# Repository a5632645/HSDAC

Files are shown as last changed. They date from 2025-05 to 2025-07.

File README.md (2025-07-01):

# CH32V305-UAC2
ch32v305fbp6 + es9018k2m + opa1678 usb dac  
> [!NOTE]
> Due to using inexpensive components, the clock has approximately a 200 Hz error. Additionally, the MCLK GPIO speed exceeds the maximum 50 MHz limit at 192 kHz.
> If desired, you can use an external crystal for the I2S MCLK clock.

> [!NOTE]
> this dac only support 48k,96k,192k 32bits, dsd and other formats are not considered

> [!NOTE]
> This DAC only supports high-speed connections, so do not connect it through a USB hub.
> Any clicks that occur are a result of the computer not sending data within a given time. Therefore, you may hear clicks during periods of high system load.
# IMAGE
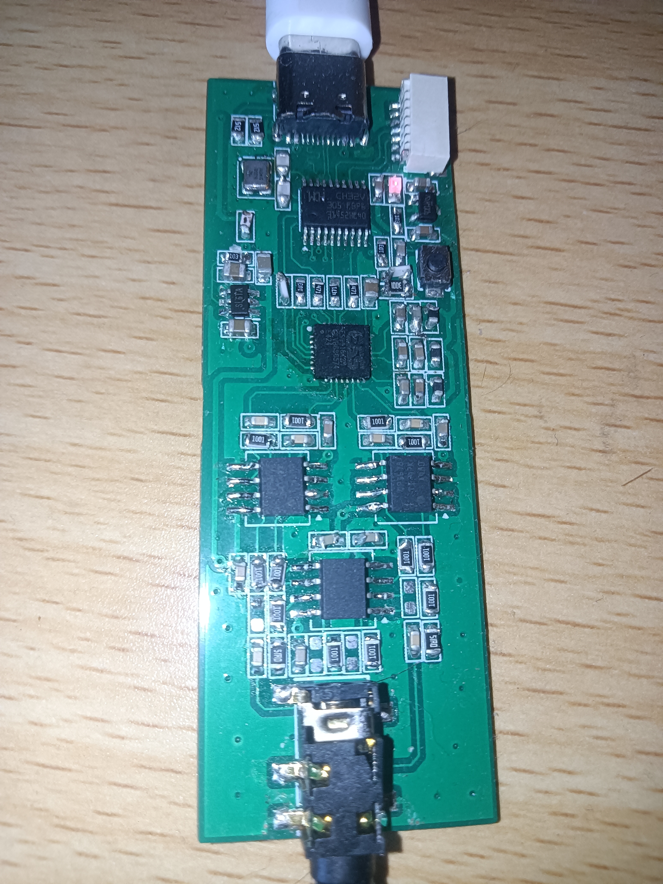
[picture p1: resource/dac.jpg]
DAC Image


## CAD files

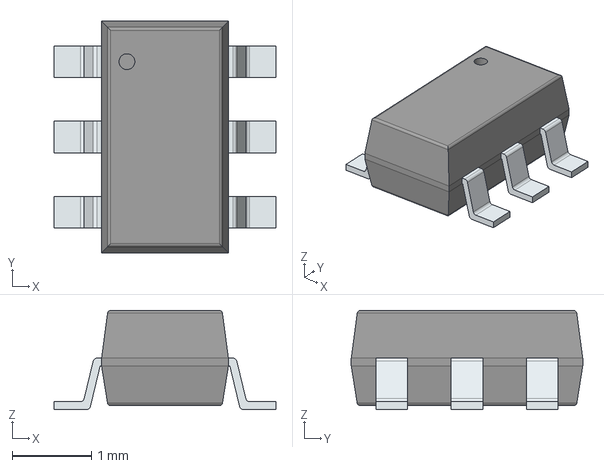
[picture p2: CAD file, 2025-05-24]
hardware/3rd/3d/SGM3204YN6G_TR.stp
2.80 x 2.92 x 1.25 mm
PinsArrayLR

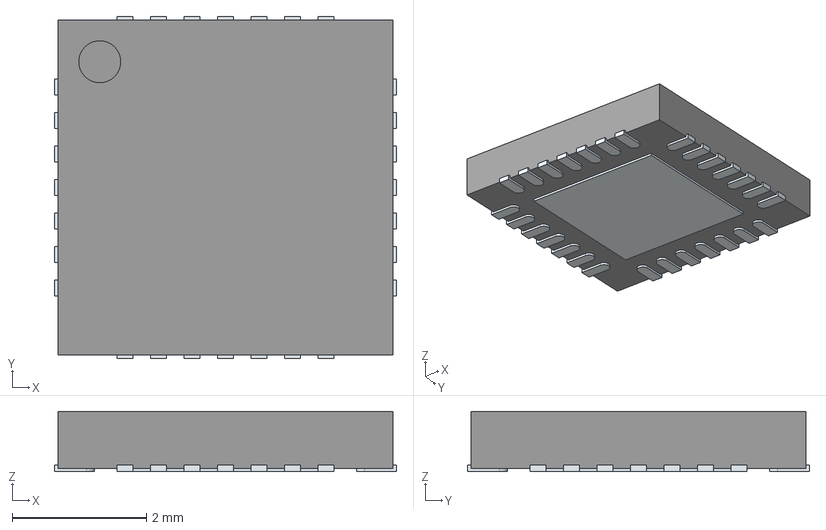
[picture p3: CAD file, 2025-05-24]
hardware/3rd/3d/ES9018K2M.stp
5.10 x 5.10 x 0.9 mm
ThermalPin
PinsArrayLR
PinsArrayTB

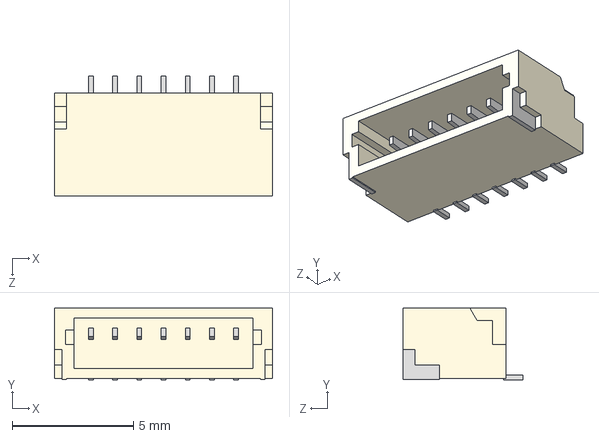
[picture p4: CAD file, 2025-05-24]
hardware/3rd/3d/SM07B-SRSS-TB_LF__SN_.stp
9.00 x 2.96 x 4.95 mm

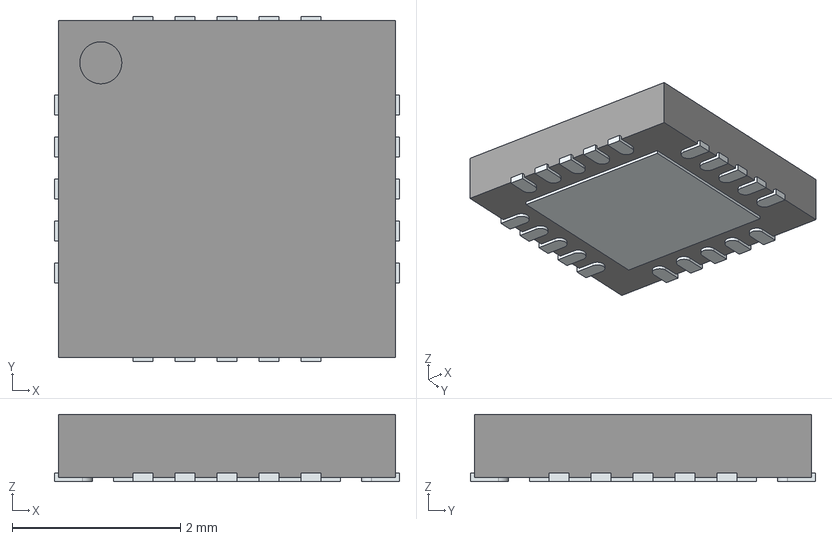
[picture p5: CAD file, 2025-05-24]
hardware/3rd/3d/TPA6130A2RTJR.stp
4.10 x 4.10 x 0.8 mm
ThermalPin
PinsArrayLR
PinsArrayTB

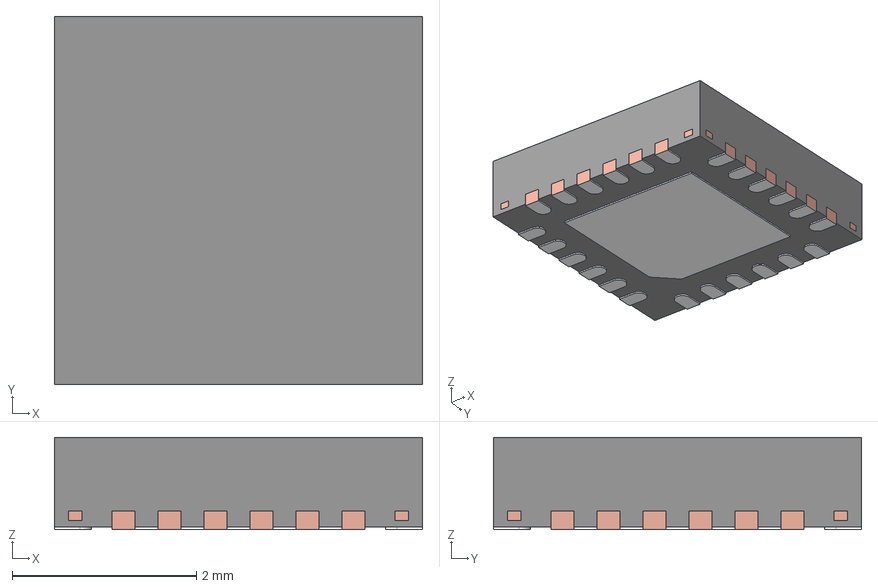
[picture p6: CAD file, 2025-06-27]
hardware/3rd/3d/TPS65131RGER.stp
4.00 x 4.00 x 1.00 mm
BODY-QFN
FRAME-RGE0024B
PIN1-ID

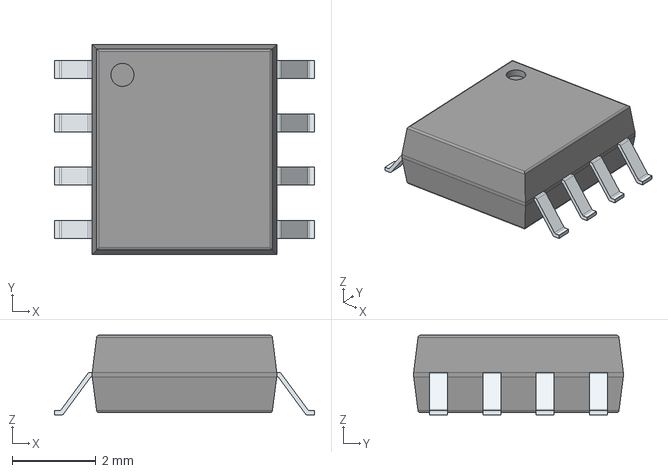
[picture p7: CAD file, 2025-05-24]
hardware/3rd/3d/M62429FP.stp
6.20 x 5.00 x 1.90 mm
PinsArrayLR

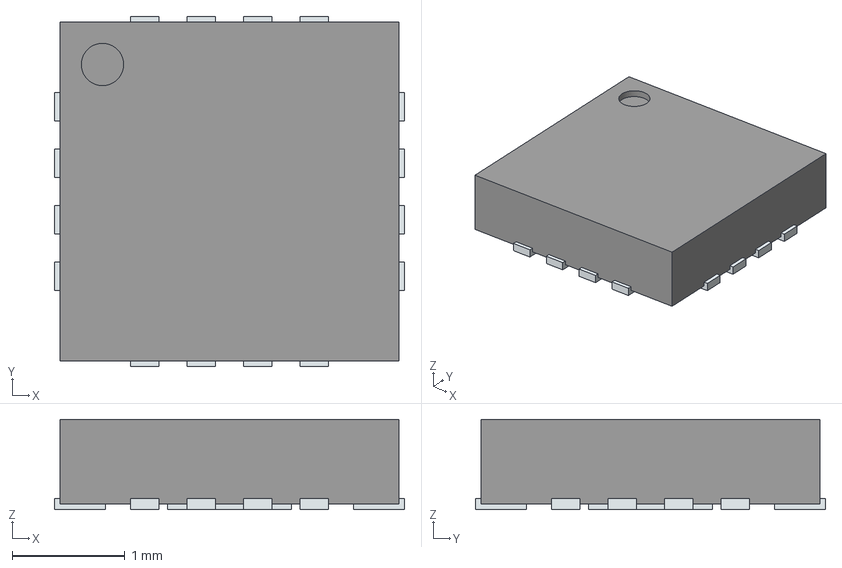
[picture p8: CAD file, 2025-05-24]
hardware/3rd/3d/MAX97220AETE+T.stp
3.10 x 3.10 x 0.8 mm
ThermalPin
PinsArrayLR
PinsArrayTB

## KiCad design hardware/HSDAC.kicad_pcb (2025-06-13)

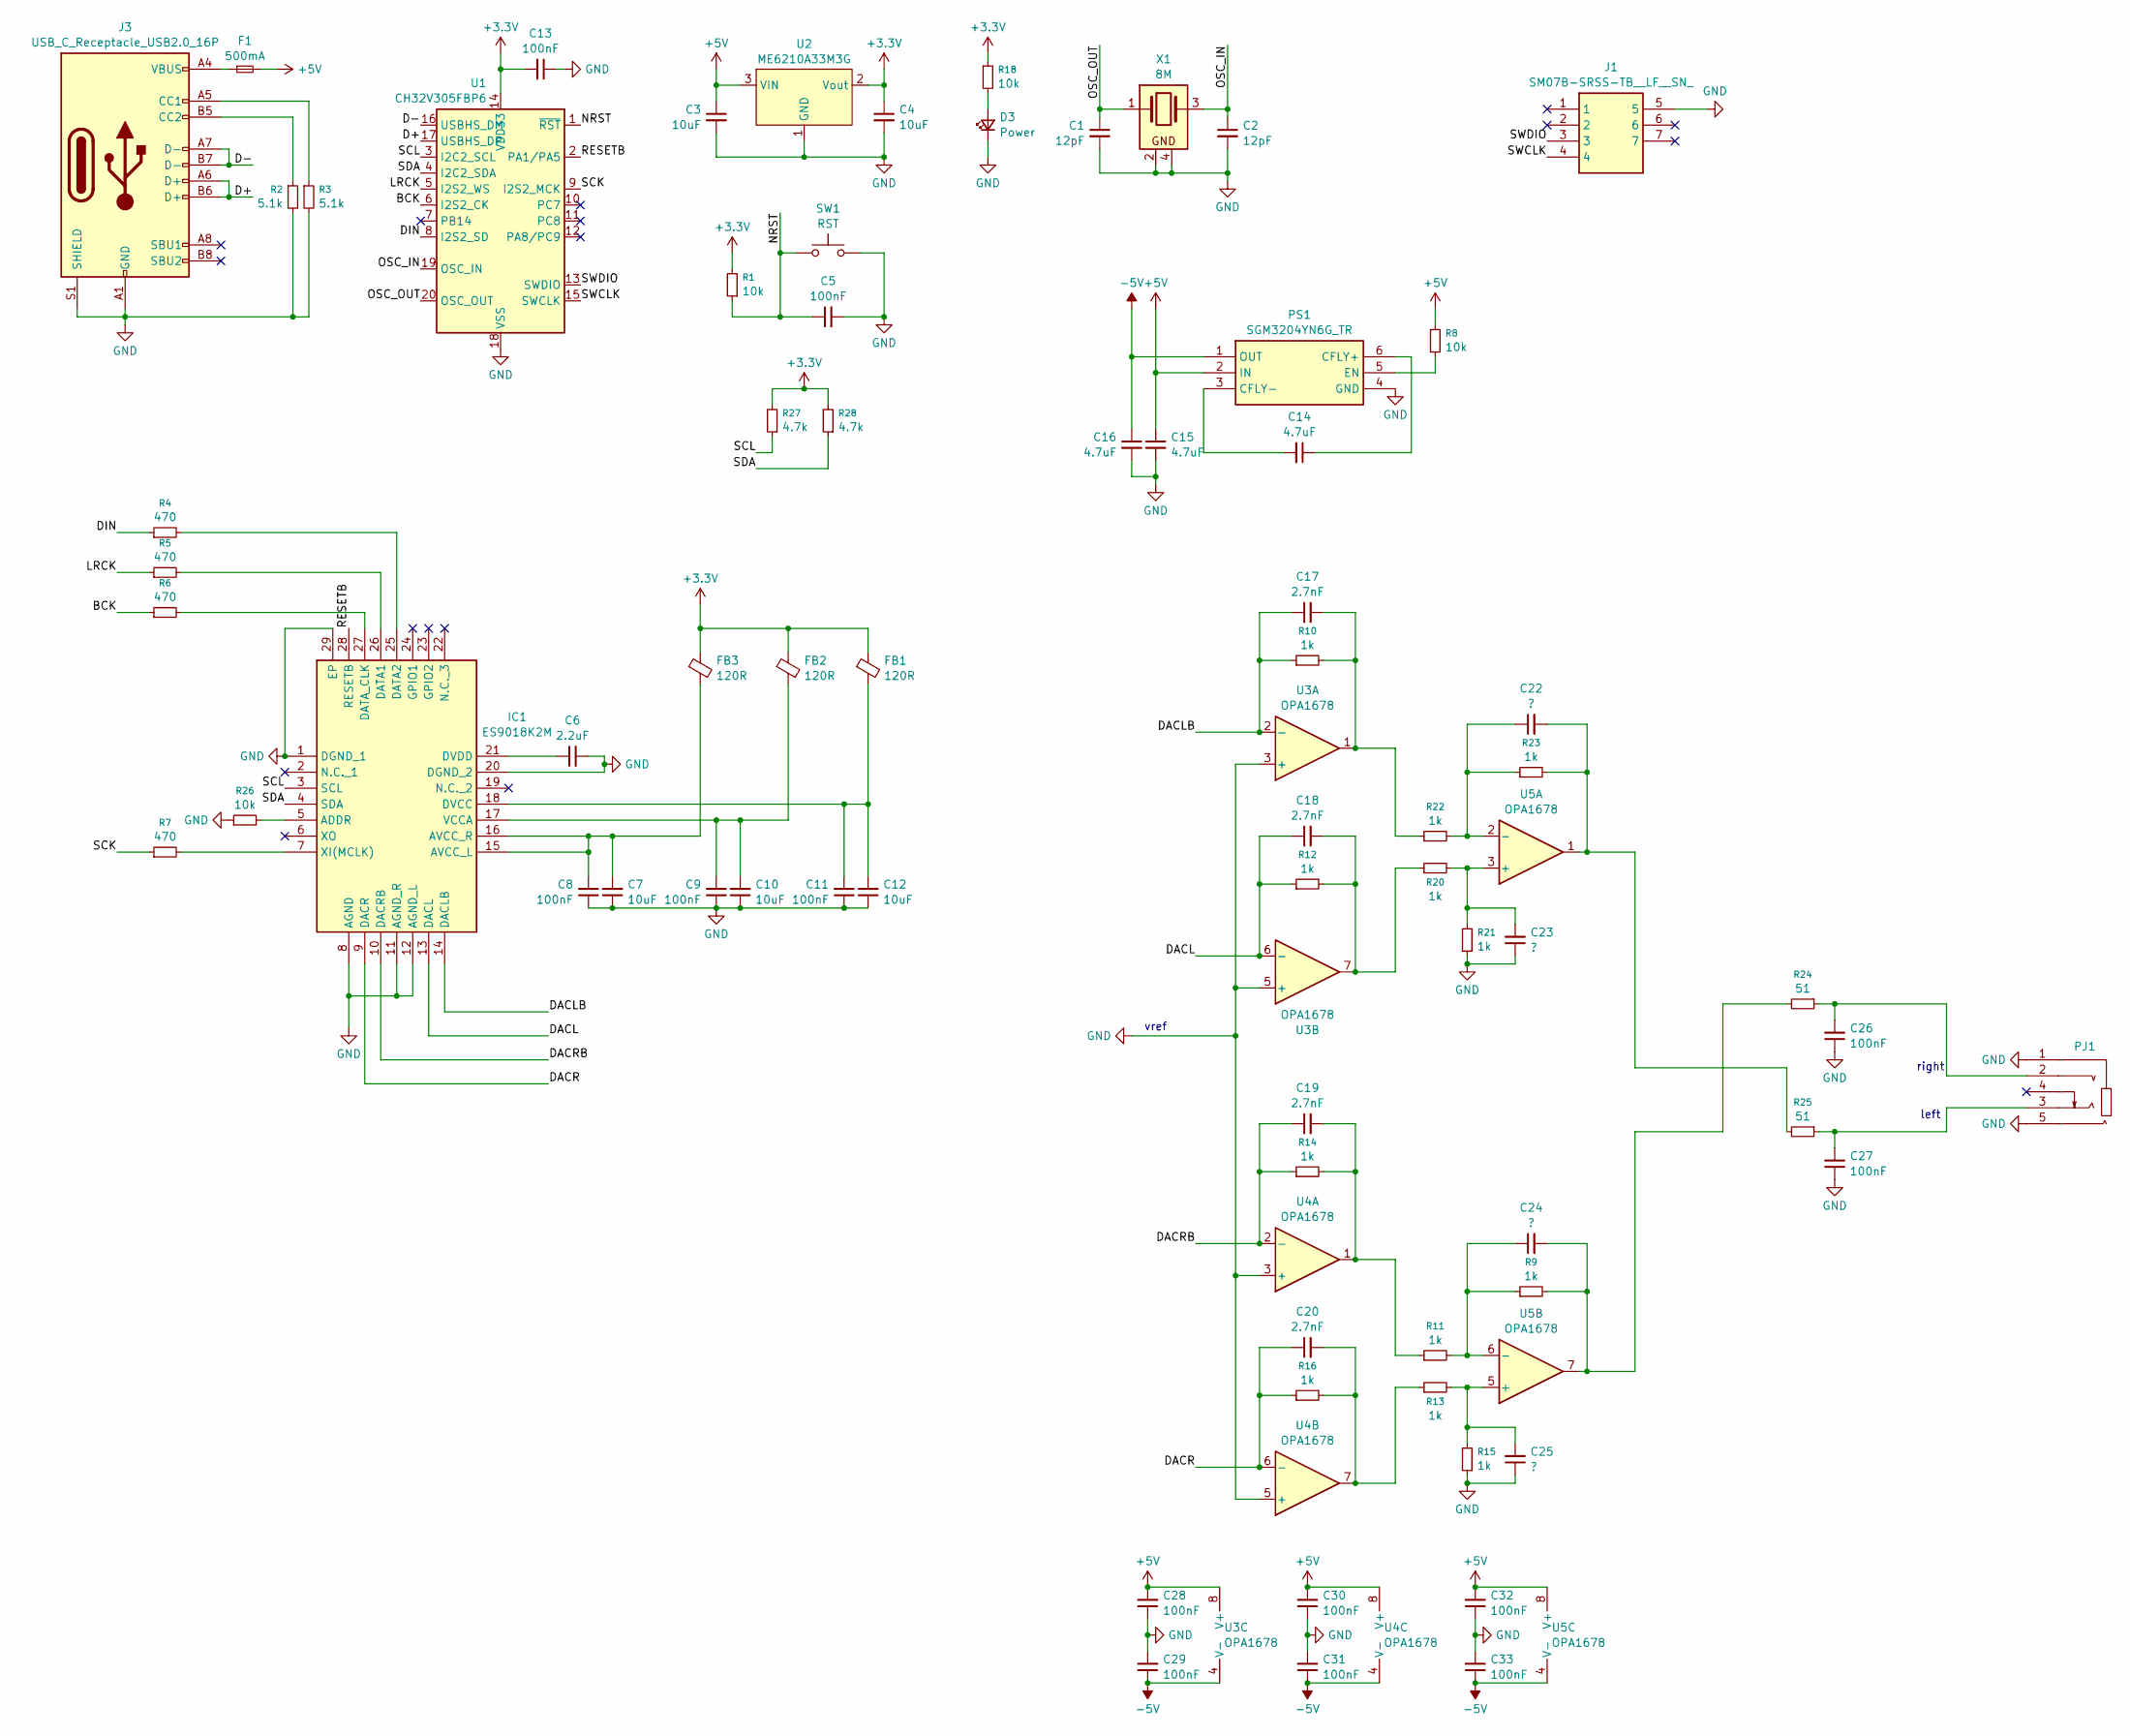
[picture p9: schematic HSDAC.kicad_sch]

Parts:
C1, C2: 12pF; C_0603_1608Metric_Pad1.05x0.95mm_HandSolder
C3, C4, C7, C10, C12: 10uF; C_0603_1608Metric_Pad1.05x0.95mm_HandSolder
C5, C8, C9, C11, C13, C26, C27, C28, C29, C30, C31, C32, C33: 100nF; C_0603_1608Metric_Pad1.05x0.95mm_HandSolder
C6: 2.2uF; C_0603_1608Metric_Pad1.05x0.95mm_HandSolder
C14, C15, C16: 4.7uF; C_0603_1608Metric_Pad1.05x0.95mm_HandSolder
C17, C18, C19, C20: 2.7nF; C_0603_1608Metric_Pad1.05x0.95mm_HandSolder
C22, C23, C24, C25: ?; C_0603_1608Metric_Pad1.05x0.95mm_HandSolder
D3: Power; LED_0805_2012Metric
F1: 500mA; Fuse_0603_1608Metric
FB1, FB2, FB3: 120R; Ferrite_0603_1608Metric
IC1: ES9018K2M; QFN50P500X500X90-29N-D; Manufacturer_Part_Number ES9018K2M; Mouser Part Number 460-ES9018K2M
J1: SM07B-SRSS-TB__LF__SN_; SM07B-SRSS-TB; Manufacturer_Part_Number SM07B-SRSS-TB (LF)(SN)
J3: USB_C_Receptacle_USB2.0_16P; USB_C_Receptacle_G-Switch_GT-USB-7010ASV
PJ1: AUDIO-IN-SMD_PJ-327A_C22355751; Manufacturer Part PJ-327A; LCSC Part Name PJ-327A
PS1: SGM3204YN6G_TR; SOT95P280X125-6N; Manufacturer_Part_Number SGM3204YN6G/TR
R1, R8, R18, R26: 10k; R_0603_1608Metric_Pad0.98x0.95mm_HandSolder
R2, R3: 5.1k; R_0603_1608Metric_Pad0.98x0.95mm_HandSolder
R4, R5, R6, R7: 470; R_0603_1608Metric_Pad0.98x0.95mm_HandSolder
R9, R10, R11, R12, R13, R14, R15, R16, R20, R21, R22, R23: 1k; R_0603_1608Metric_Pad0.98x0.95mm_HandSolder
R24, R25: 51; R_0603_1608Metric_Pad0.98x0.95mm_HandSolder
R27, R28: 4.7k; R_0603_1608Metric_Pad0.98x0.95mm_HandSolder
SW1: RST; SW-SMD_L4.0-W3.0-LS4.8-1
U1: CH32V305FBP6; TSSOP-20_4.4x6.5mm_P0.65mm
U2: ME6210A33M3G; SOT-23
U3, U4, U5: OPA1678; SOIC-8_3.9x4.9mm_P1.27mm
X1: 8M; Crystal_SMD_3225-4Pin_3.2x2.5mm

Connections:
+3.3V: C4.1, C13.2, FB1.1, FB2.1, FB3.1, R1.2, R18.1, R27.2, R28.2, U1.14 (VDD33), U2.2 (Vout)
+5V: C3.1, C15.1, C28.2, C30.2, C32.2, F1.2, PS1.2 (IN), R8.2, U2.3 (VIN), U3.8 (V+), U4.8 (V+), U5.8 (V+)
-5V: C16.1, C29.1, C31.1, C33.1, PS1.1 (OUT), U3.4 (V-), U4.4 (V-), U5.4 (V-)
/BCK: R6.1, U1.6 (I2S2_CK)
/D+: J3.A6 (D+), J3.B6 (D+), U1.17 (USBHS_DP)
/D-: J3.A7 (D-), J3.B7 (D-), U1.16 (USBHS_DM)
/DACL: C18.1, IC1.13 (DACL), R12.1, U3.6 (-)
/DACLB: C17.1, IC1.14 (DACLB), R10.1, U3.2 (-)
/DACR: C20.1, IC1.9 (DACR), R16.1, U4.6 (-)
/DACRB: C19.1, IC1.10 (DACRB), R14.1, U4.2 (-)
/DIN: R4.1, U1.8 (I2S2_SD)
/LRCK: R5.1, U1.5 (I2S2_WS)
/NRST: C5.1, R1.1, SW1.1, U1.1 (~RST)
/OSC_IN: C2.1, U1.19 (OSC_IN), X1.3
/OSC_OUT: C1.1, U1.20 (OSC_OUT), X1.1
/RESETB: IC1.28 (RESETB), U1.2 (PA1/PA5)
/SCK: R7.1, U1.9 (I2S2_MCK)
/SCL: IC1.3 (SCL), R27.1, U1.3 (I2C2_SCL)
/SDA: IC1.4 (SDA), R28.1, U1.4 (I2C2_SDA)
/SWCLK: J1.4, U1.15 (SWCLK)
/SWDIO: J1.3, U1.13 (SWDIO)
GND: C1.2, C2.2, C3.2, C4.2, C5.2, C6.2, C7.1, C8.1, C9.1, C10.1, C11.1, C12.1, C13.1, C15.2, C16.2, C23.1, C25.1, C26.1, C27.1, C28.1, C29.2, C30.1, C31.2, C32.1, C33.2, D3.1 (K), IC1.1 (DGND_1), IC1.8 (AGND), IC1.11 (AGND_R), IC1.12 (AGND_L), IC1.20 (DGND_2), IC1.29 (EP), J1.5, J3.A1 (GND), J3.A12 (GND), J3.B1 (GND), J3.B12 (GND), J3.S1 (SHIELD), PJ1.1, PJ1.5, PS1.4 (GND), R2.2, R3.2, R15.1, R21.1, R26.1, SW1.2, U1.18 (VSS), U2.1 (GND), U3.3 (+), U3.5 (+), U4.3 (+), U4.5 (+), X1.2, X1.4
unnamed: C17.2, R10.2, R22.1, U3.1
unnamed: C18.2, R12.2, R20.1, U3.7
unnamed: C19.2, R11.1, R14.2, U4.1
unnamed: C20.2, R13.1, R16.2, U4.7
unnamed: C22.2, R23.2, R25.2, U5.1
unnamed: C24.2, R9.2, R24.2, U5.7
unnamed: C26.2, PJ1.2, R24.1
unnamed: C27.2, PJ1.3, R25.1
unnamed: D3.2 (A), R18.2
unnamed: F1.1, J3.A4 (VBUS), J3.A9 (VBUS), J3.B4 (VBUS), J3.B9 (VBUS)
unnamed: IC1.5 (ADDR), R26.2
unnamed: C7.2, C8.2, FB3.2, IC1.15 (AVCC_L), IC1.16 (AVCC_R)
unnamed: IC1.26 (DATA1), R5.2
unnamed: IC1.25 (DATA2), R4.2
unnamed: IC1.27 (DATA_CLK), R6.2
unnamed: C11.2, C12.2, FB1.2, IC1.18 (DVCC)
unnamed: C6.1, IC1.21 (DVDD)
unnamed: C9.2, C10.2, FB2.2, IC1.17 (VCCA)
unnamed: IC1.7 (XI(MCLK)), R7.2
unnamed: J3.A5 (CC1), R3.1
unnamed: J3.B5 (CC2), R2.1
unnamed: C14.1, PS1.6 (CFLY+)
unnamed: C14.2, PS1.3 (CFLY-)
unnamed: PS1.5 (EN), R8.1
unnamed: C23.2, R20.2, R21.2, U5.3 (+)
unnamed: C22.1, R22.2, R23.1, U5.2 (-)
unnamed: C25.2, R13.2, R15.2, U5.5 (+)
unnamed: C24.1, R9.1, R11.2, U5.6 (-)

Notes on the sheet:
right
left
vref

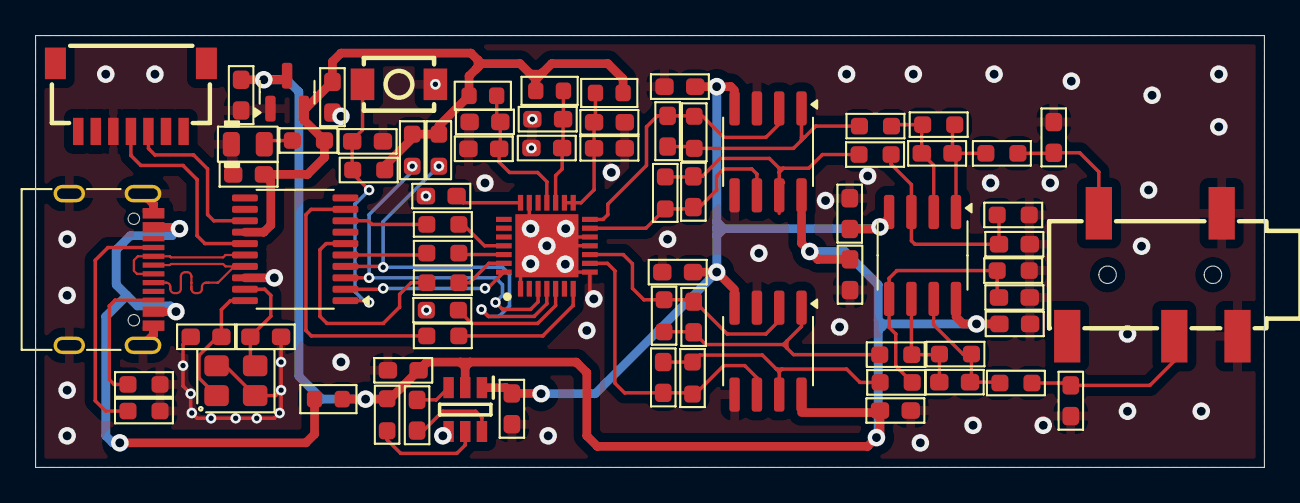
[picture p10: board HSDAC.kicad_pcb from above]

Board: 2 copper layers, 70.0 x 24.6 mm, 75 parts (0 on the bottom side), 50 nets.

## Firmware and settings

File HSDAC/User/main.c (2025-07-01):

#include "debug.h"
#include "codec.h"
#include <math.h>
#include "tick.h"
#include "ch32v30x_gpio.h"
#include "usb/ch32v30x_usbhs_device.h"
#include "hid_queue.h"

static void ES9018K_Init(void) {
    Codec_Init();
    GPIO_WriteBit(GPIOA, GPIO_Pin_1, Bit_RESET);
    Delay_Ms(100);
    GPIO_WriteBit(GPIOA, GPIO_Pin_1, Bit_SET);
    Delay_Ms(100);

    // 尼玛，手册里寄存器写 #12 ,然后是0x12, cnm
    Codec_PollWrite(0, 0xf1);
    Delay_Ms(100);
    Codec_PollWrite(0, 0xf0);
    Delay_Ms(100);
    Codec_PollWrite(1, 0b10000000);
}

extern volatile uint32_t max_uac_len_ever;
extern volatile uint32_t min_uac_len_ever;
extern uint32_t mesured_dma_sample_rate_;
extern uint32_t mesured_usb_sample_rate_;
extern float report_fs_;
extern uint8_t vol_[];

int main(void) {
    NVIC_PriorityGroupConfig(NVIC_PriorityGroup_2);
    SystemCoreClockUpdate();
    Delay_Init();
    Tick_Init();

    ES9018K_Init();
    USBHS_RCC_Init();
    USBHS_Device_Init(ENABLE);

    uint32_t t = Tick_GetTick();
    uint32_t t2 = Tick_GetTick();
    for (;;) {
        uint32_t ct = Tick_GetTick();
        if ((ct - t) > 1000) {
            t = ct;

            if (USBHS_DevEnumStatus) {
                printf("[fs]usb: %luHz, dma: %luHz, fb:%luHz\n\r", mesured_usb_sample_rate_, mesured_dma_sample_rate_, (uint32_t)report_fs_);
                printf("[uac]len: %lu, min: %lu, max:%lu\n\r\n\r", Codec_GetUACBufferLen(), min_uac_len_ever, max_uac_len_ever);
            }
        }

        if ((ct - t2) > 10) {
            t2 = ct;
            if (min_uac_len_ever < 256)
                ++min_uac_len_ever;
            if (max_uac_len_ever > 0)
                --max_uac_len_ever;
        }

        Codec_CheckVolumeEvent();

        uint32_t len;
        HID_Queue_Read(&g_hid_queue, &len);
        for (uint32_t i = 0; i < len; ++i) {
            struct HID_Event* e = HID_Queue_GetItem(&g_hid_queue, i);
            if (USBHS_DevEnumStatus) {
                printf("[hid]type: %d, reg: %d, val: %d\n\r", (int)e->type, e->reg, e->val);
            }

            if (e->type == 0) {
                // dac param setting
                Codec_PollWrite(e->reg, e->val);
                Delay_Ms(10);
            }
            else if (e->type == 1 && e->reg == 0x12 && e->val == 0x34) {
                // firmware update
                RCC_APB1PeriphClockCmd( RCC_APB1Periph_PWR | RCC_APB1Periph_BKP, ENABLE );
                BKP_TamperPinCmd( DISABLE );
                PWR_BackupAccessCmd( ENABLE );
                BKP_ClearFlag();

                BKP_WriteBackupRegister(BKP_DR1, 0x1234);
                BKP_WriteBackupRegister(BKP_DR2, 0x5678);
                Codec_DeInit();
                USBHS_Device_Init(DISABLE);
                NVIC_SystemReset();
            }
            else if (e->type == 2) {
                // latency setting
                uint32_t pos = e->reg << 8 | e->val;
                Codec_SetLatencyPos(pos);
            }
        }
        HID_Queue_Finish(&g_hid_queue, len);
    }
}

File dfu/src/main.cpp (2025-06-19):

#include "MainComponent.h"

//==============================================================================
class GuiAppApplication final : public juce::JUCEApplication
{
public:
    //==============================================================================
    GuiAppApplication() {}

    // We inject these as compile definitions from the CMakeLists.txt
    // If you've enabled the juce header with `juce_generate_juce_header(<thisTarget>)`
    // you could `#include <JuceHeader.h>` and use `ProjectInfo::projectName` etc. instead.
    const juce::String getApplicationName() override       { return JUCE_APPLICATION_NAME_STRING; }
    const juce::String getApplicationVersion() override    { return JUCE_APPLICATION_VERSION_STRING; }
    bool moreThanOneInstanceAllowed() override             { return true; }

    //==============================================================================
    void initialise (const juce::String& commandLine) override
    {
        // This method is where you should put your application's initialisation code..
        juce::ignoreUnused (commandLine);

        mainWindow.reset (new MainWindow (getApplicationName()));
    }

    void shutdown() override
    {
        // Add your application's shutdown code here..

        mainWindow = nullptr; // (deletes our window)
    }

    //==============================================================================
    void systemRequestedQuit() override
    {
        // This is called when the app is being asked to quit: you can ignore this
        // request and let the app carry on running, or call quit() to allow the app to close.
        quit();
    }

    void anotherInstanceStarted (const juce::String& commandLine) override
    {
        // When another instance of the app is launched while this one is running,
        // this method is invoked, and the commandLine parameter tells you what
        // the other instance's command-line arguments were.
        juce::ignoreUnused (commandLine);
    }

    //==============================================================================
    /*
        This class implements the desktop window that contains an instance of
        our MainComponent class.
    */
    class MainWindow final : public juce::DocumentWindow
    {
    public:
        explicit MainWindow (juce::String name)
            : DocumentWindow (name,
                              juce::Desktop::getInstance().getDefaultLookAndFeel()
                                                          .findColour (backgroundColourId),
                              allButtons)
        {
            setUsingNativeTitleBar (true);
            setContentOwned (new MainComponent(), true);

           #if JUCE_IOS || JUCE_ANDROID
            setFullScreen (true);
           #else
            setResizable (true, true);
            centreWithSize (getWidth(), getHeight());
           #endif

            setVisible (true);
        }

        void closeButtonPressed() override
        {
            // This is called when the user tries to close this window. Here, we'll just
            // ask the app to quit when this happens, but you can change this to do
            // whatever you need.
            getInstance()->systemRequestedQuit();
        }

        /* Note: Be careful if you override any DocumentWindow methods - the base
           class uses a lot of them, so by overriding you might break its functionality.
           It's best to do all your work in your content component instead, but if
           you really have to override any DocumentWindow methods, make sure your
           subclass also calls the superclass's method.
        */

    private:
        JUCE_DECLARE_NON_COPYABLE_WITH_LEAK_DETECTOR (MainWindow)
    };

private:
    std::unique_ptr<MainWindow> mainWindow;
};

//==============================================================================
// This macro generates the main() routine that launches the app.
START_JUCE_APPLICATION (GuiAppApplication)

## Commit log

2025-05-24 usb cdc!理解了一些usb但还是不够熟练（；´д｀）ゞ
2025-05-29 集成了CDC调试，必须修好自适应采样率
2025-05-30 uac!至少能跑了?
2025-05-31 why反馈端点也不行
2025-05-31 非常好时钟，使我偏差+-300hz，可惜反馈端点太监了不对
2025-06-01 你说得对，但是我的USB声卡没有反馈端点，感觉不如elipitic blep重采样
2025-06-02 perfect 48k&96k,192k虽然显示一直溢出但声音也是连续的？
2025-06-02 what the hell is the bug from!
    [codec.c]
2025-06-02 what the hell is the bug come from 2? fuck windows usb
    [codec.c]
2025-06-03 感觉不如重采样通用...
2025-06-03 no, jitterh和反馈明显更好好吧
2025-06-03 我在不HIFI和眼力挑战中获得了0分的成绩，你也来试试吧
2025-06-04 总线速度不够？改为3倍频了，MCLK到GPIO引脚上限也能工作？
2025-06-04 更新 README.md
2025-06-13 修复声道和运放封装错误
    [HSDAC.kicad_pcb, HSDAC.kicad_sch]
2025-06-14 omg,我合并错了
2025-06-16 hid通信队列成功
2025-06-18 添加了HID bootloader
2025-06-27 barely can use
    [TPS65131RGER.stp]
2025-07-01 shorten the buffer size
    [codec.c, main.c]
2025-07-01 SCK的电阻和实际不一样
    [HSDAC.kicad_sch]
